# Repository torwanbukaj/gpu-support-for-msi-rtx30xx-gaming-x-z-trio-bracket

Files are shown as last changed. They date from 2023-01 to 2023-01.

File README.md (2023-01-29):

# GPU support for MSI RTX 30xx Gaming X & Z Trio bracket

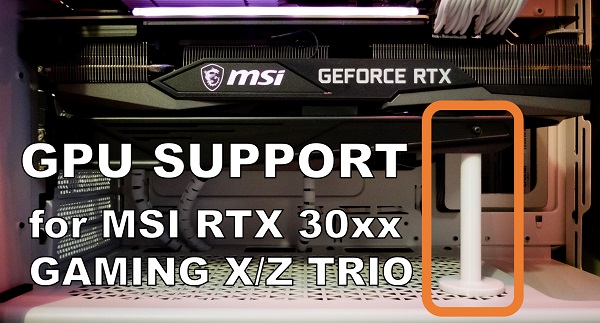
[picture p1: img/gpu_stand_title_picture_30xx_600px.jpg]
GPU support title picture


This work is licensed under a
[Creative Commons Attribution-NonCommercial-ShareAlike 4.0 International License][cc-by-nc-sa].

# Summary
This GPU support was designed to be used with anti-bending bracket which is delivered together with MSI RTX 30xx Gaming X/Z Trio. In general, the bracket does quite good anti-GPU-sagging job but depending on a PC case, it may be a bit unstable at its end (moving in horizontal plane under the weight of a GPU). It looks like these MSI brackets are not designed only for one specific GPU model but rather for a range of RTX30xx Gaming X/Z Trio GPUs  and in a result they do not really fit perfectly to every GPU. My published here model helps to increase working surface of the bracket in a place where it supports the GPU (end of the bracket). It also helps to precisely level your GPU card thanks to the thread incorporated into the design.

The support was tested only with my RTX3070 Gaming Z Trio bracket but when I watch to the following MSI's video I have a gut feeling they deliver the same anti-bending bracket with a range of 30xx Gaming Trio GPUs:

https://www.youtube.com/watch?v=a4ZdkeQ2Yjs

The bottom part total length was defined based on measurements taken in the system for which it was designed (PC case bequiet Pure Base 500DX + above mentioned GPU). If you do not have exactly the same PC case, you will have to take your own measurements and re-define value of "stand_h_total" parameter in the attached OpenSCAD generator.

You will need one M2 screw of 10-15mm length to connect the top part (hook) to the GPU bracket.

This GPU stand generator requires "threads.scad" library for generating threads. You can download it e.g., using this official OpenSCAD link:

[Link to official OpenSCAD "Threads" library](https://openscad.org/libraries.html#threads.scad)

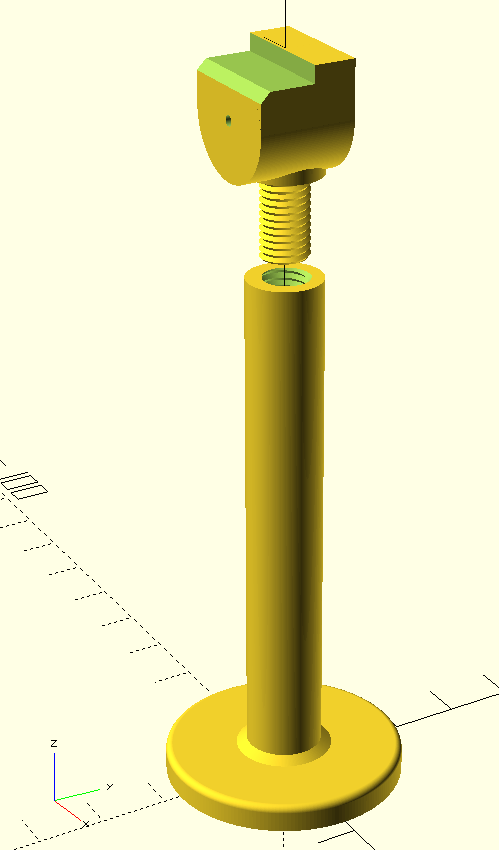
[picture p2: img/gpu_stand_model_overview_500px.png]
3D model

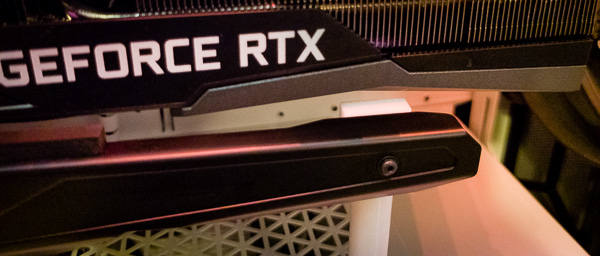
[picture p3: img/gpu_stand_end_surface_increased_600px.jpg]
Top part increasing touch surface

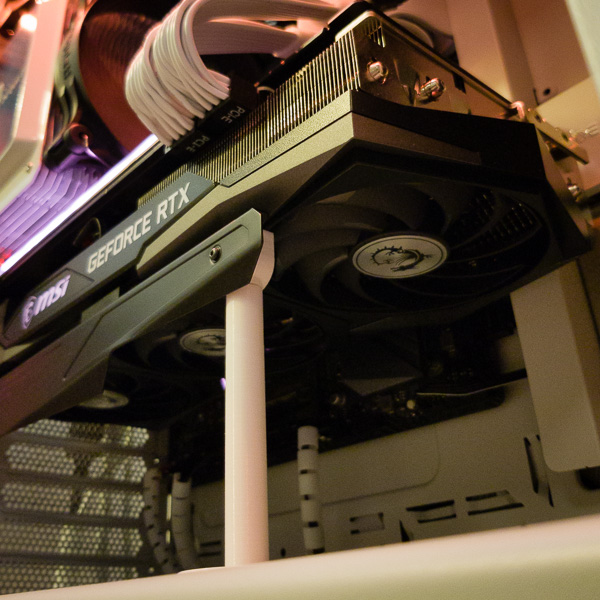
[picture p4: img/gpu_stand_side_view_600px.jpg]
GPU support - side view


# How to print

To achieve the best printing quality, the bottom part (pillar) should be printed in vertical position (standing).

If it comes to the top part (hook) I highly recommend to print it up-side-down, using 3D printed support, exactly like this:

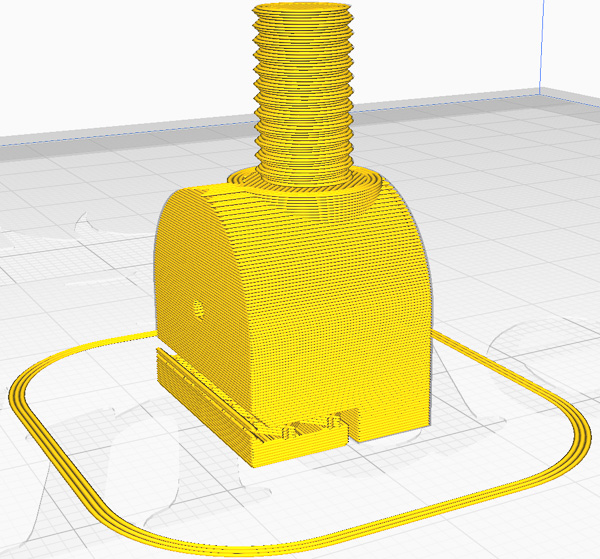
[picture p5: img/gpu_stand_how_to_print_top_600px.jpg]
How to print the top part


---
Shield: [][cc-by-nc-sa]

This work is licensed under a
[Creative Commons Attribution-NonCommercial-ShareAlike 4.0 International License][cc-by-nc-sa].

[][cc-by-nc-sa]

[cc-by-nc-sa]: http://creativecommons.org/licenses/by-nc-sa/4.0/
[cc-by-nc-sa-image]: https://licensebuttons.net/l/by-nc-sa/4.0/88x31.png
[cc-by-nc-sa-shield]: https://img.shields.io/badge/License-CC%20BY--NC--SA%204.0-lightgrey.svg

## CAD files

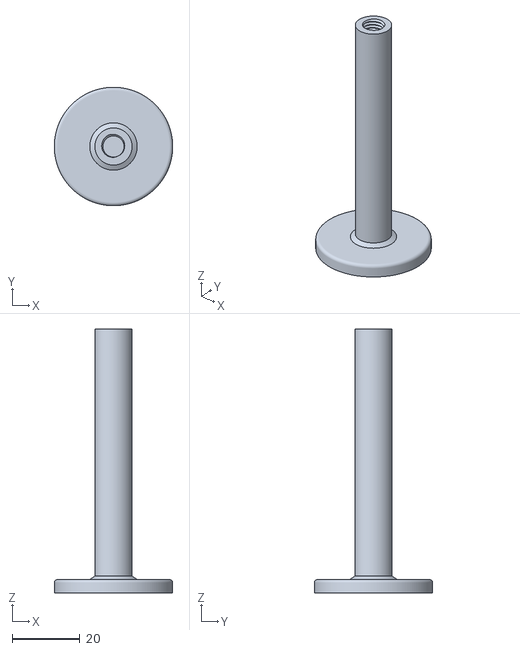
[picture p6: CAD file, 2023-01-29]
pre-generated_parts_stl/gpu_stand_bottom_msi_30xx_gaming_x_z_trio_bracket.stl
35.0 x 35.0 x 78.0

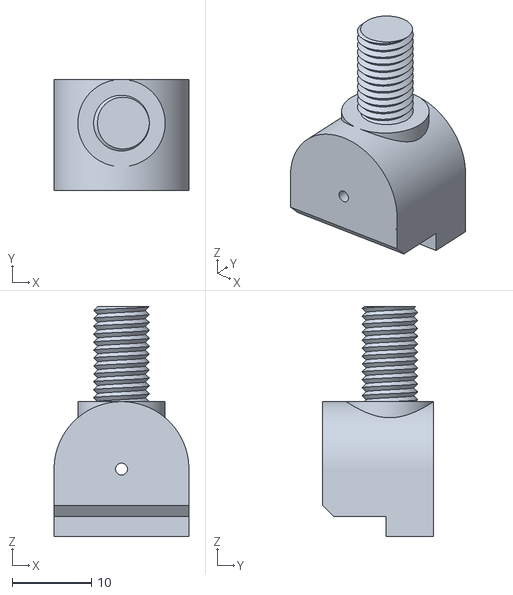
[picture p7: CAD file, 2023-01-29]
pre-generated_parts_stl/gpu_stand_top_msi_30xx_gaming_x_z_trio_bracket.stl
17.0 x 14.0 x 29.0

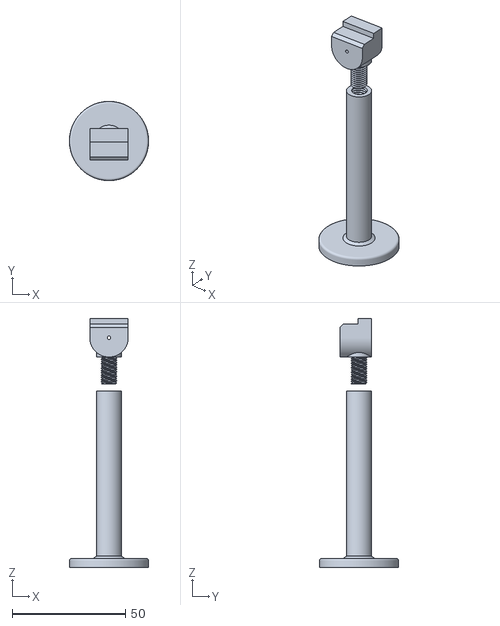
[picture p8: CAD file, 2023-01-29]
pre-generated_parts_stl/gpu_stand_overview_msi_30xx_gaming_x_z_trio_bracket.stl
35.0 x 35.0 x 110.0

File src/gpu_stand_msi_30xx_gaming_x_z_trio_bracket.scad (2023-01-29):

// GPU stand for MSI RTX 30xx Gaming X/Z Trio metal anti-bending bracket
// by torwan @ January 29th, 2023

// Description / Hints:
// - See also on https://www.thingiverse.com/thing:5818388
// - All dimensions in [mm].
// - Hook dimensions should work fine with original MSI anti-bending
//   bracket which is added to MSI RTX 30xx Gaming X or Z Trio GPUs.
// - The model was successfully tested only with MSI RTX 3070 Gaming
//   Z Trio GPU installed inside bequiet Pure Base 500DX PC case.
// - You will need to tune stand_h_total to fit your PC case system 
//   (take your own measurements and adjust the parameter before
//   printing the bottom part.
// - The hook (upper part) is supposed to be mounted to the GPU bracket
//   with use of M2 screw.
// - This generator requires "threads.scad" library for generating threads.
//   You can download it e.g., using this official OpenSCAD link:
//   https://openscad.org/libraries.html#threads.scad
//
// This work is licensed under a Creative Commons
// Attribution-NonCommercial-ShareAlike 4.0 International License.

use <threads.scad>  // this is mandatory (see description above)

// Main parameters
pillar_dia = 11;       // 11, make sure this is not larger than hook_width
pillar_thread_dia = 7; // 7

// Hook dimensions
hook_upper_step_off = 2.5; // 2.5, deepness of an upper step-off
hook_step_off_start = 8;   // 8, measured from the GPU bracket side
hook_width = 17;           // 17, hook width
hook_height = 17;          // 17, hook height (without thread)
hook_length_min = 3;       // 3, minimum space between the GPU bracket
                           // and the thread base (~bottom pillar sidewall) 
hook_screw_dia = 1.5;      // 1.5, for screw connecting the GPU bracket
                           // with the hook
hook_thread_l = 12;        // 12, length of the hook thread
chamfer_block = 2;         // 2, chamfer square block sidewall


// Bottom stand/pillar dimensions
stand_h_total = 78;        // 78
stand_base_dia = 35;       // 35
stand_base_h = 4;          // 4
stand_base_radius = 1;     // 1, stand base smoothing radius
stand_mid_dia = 14;        // 14, for transition between the stand base
                           // and pillar
stand_mid_h = 5;           // 5, transition end-height (measured from
                           // the bottom of the stand base
                           
// Supporting auto-calculated dimensions (do not change)
stand_thread_h = hook_thread_l * 1.5;
hook_length = hook_length_min + pillar_dia;
hook_cyl_off = (hook_width - hook_height)/2;

// Other helping parameters
$fn = 200;  // min. 200 recommended
cc = 0.01;  // for improving a preview


// ### GENERATE THE STAND PARTS
// Call show_me module with one of the possible what_to_show values:
//  - 0 - shows an overview of the whole stand (bottom + top parts)
//  - 1 - shows only the bottom (pillar) part
//  - 2 - shows only the top (hook) part

show_me(what_to_show = 0);



// ####################################################################
// Below are the generator modules. Do not modify if not really needed.

module show_me(what_to_show = 0) {
    
    if (what_to_show == 0) {
        gpu_stand_bottom();
        
        translate([0,
                   pillar_dia/2,
                   stand_h_total
                   + hook_thread_l
                   + hook_height/2 + 3])
            rotate([0, 180, 0])
                gpu_stand_top();
    }
 
    if (what_to_show == 1) {
        gpu_stand_bottom();
    }
 
    if (what_to_show == 2) {
        gpu_stand_top();
    }
}

// GPU stand top part (hook)
module gpu_stand_top(){

    difference() {
        union() {
            // Hook root body
            rotate([90, 0, 0])
                hull() {
                    translate([-hook_cyl_off, 0, hook_length/2])
                        cylinder(d = hook_height,
                                 h = hook_length,
                                 center = true);
                    translate([+hook_cyl_off, 0, hook_length/2])
                        cylinder(d = hook_height,
                                 h = hook_length,
                                 center = true);
                }
            // Upper half of the hook body
            translate([0, -hook_length/2, -hook_height/4])
                cube([hook_width-cc,
                      hook_length-cc,
                      hook_height/2-cc],
                     center = true);  

            // Thread base
            translate([0, -pillar_dia/2, 0])
                cylinder(d = pillar_dia, h = hook_height/2);    
               
            // Thread
            translate([0, -pillar_dia/2, 0])
                ScrewThread(pillar_thread_dia,
                            hook_height/2+hook_thread_l,
                            pitch=0,
                            tooth_angle=45,
                            tolerance=0.1,
                            tip_height=0,
                            tooth_height=0,
                            tip_min_fract=0);
        }
        // Hook chamfer
        rotate([90, 0, 0])
            cylinder(d = hook_screw_dia, h = hook_length+cc);
        translate([0, -hook_length, -hook_height/2+hook_upper_step_off])
            rotate([45, 0, 0])
                cube([hook_width,
                      chamfer_block,
                      chamfer_block],
                     center = true);
        
        // Step-off cut-out
        translate([0,
                   -1.5*hook_length+hook_step_off_start,
                   hook_upper_step_off/2-hook_height/2])
            cube([hook_width,
                  hook_length,
                  hook_upper_step_off],
                 center = true);
    } // difference
}

// GPU stand bottom part (pillar with foot)
module gpu_stand_bottom(){

    // Pillar body
    translate([0, 0, 0])
        cylinder(d = pillar_dia, h = stand_h_total - stand_thread_h);
    
    // Pillar screw hole
    translate([0, 0, stand_h_total - stand_thread_h])
        ScrewHole(pillar_thread_dia,
              stand_thread_h,
              position=[0,0,0],
              rotation=[0,0,0],
              pitch=0,
              tooth_angle=45,
              tolerance=0.2,
              tooth_height=0) 
                cylinder(d = pillar_dia, h = stand_thread_h);

    difference() {  
        // Foot body
        rotate_extrude(angle = 360) 
            offset(r = stand_base_radius){ 
                translate([stand_base_radius, 0, 0])    
                    polygon([[0, -stand_base_h+stand_base_radius],
                             [stand_base_dia/2-2*stand_base_radius,
                              -stand_base_h+stand_base_radius],
                             [stand_base_dia/2-2*stand_base_radius,
                              stand_base_h-stand_base_radius],
                             [0, stand_base_h-stand_base_radius]]); 
            }
            
        // Cutting out unnecessary foot bottom half           
        translate([-stand_base_dia/2,
                   -stand_base_dia/2,
                    -stand_base_h-cc])
            cube([stand_base_dia, stand_base_dia, stand_base_h+2*cc]);  
    }

    // Smoothing transition between the base and the pillar
    rotate_extrude(angle = 360) 
        polygon([[pillar_dia/2, stand_base_h],
                 [stand_mid_dia/2, stand_base_h],
                 [pillar_dia/2, stand_mid_h]]);
}

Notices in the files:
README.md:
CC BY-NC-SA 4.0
